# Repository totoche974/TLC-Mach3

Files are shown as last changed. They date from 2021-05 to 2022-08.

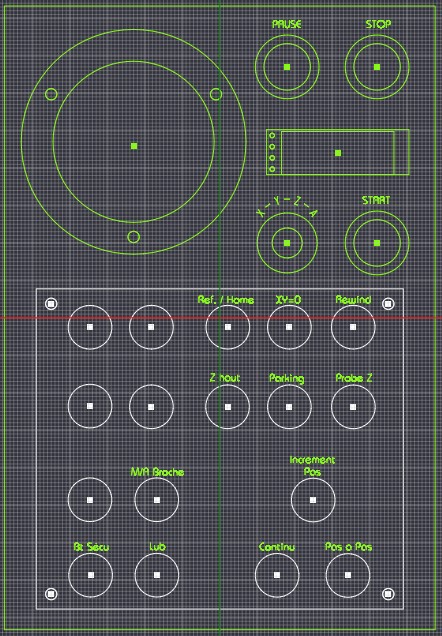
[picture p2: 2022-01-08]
doc/face_avant_TLC.jpg

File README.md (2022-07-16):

# TLC-Mach3

Ce projet héberge tout ce qu'il faut pour construire une télécommande de CNC.

## Composition de la télécommande

- 16 touches configurable via le fichier commandClavier.cpp
- 3 touches STOP , PAUSE , START 
- 1 touche de sécurité
- 1 afficheur LCD 
- 1 manivelle encodeur pour de déplacement des axes XYZA
- 1 sélecteur d'axe rotatif 4 positions
- 1 bouton poussoir pour la visu de la batterie

TODO : image montage fritzing

# Lancer le projet

## Environnement de travail

VS Code
plateformIO
Les lib externes utilisés et leur rôle

doxygen

## Génération de la documentation

Pour générer la documentation :
```shell
doxygen doxygen.config
```

# Matériel

## Schéma

Schéma de la carte "ESP32 HUZZAH FEATHER32"

Nous utilisons la carte Adafruit Huzzah ESP32 Feather:
Adafruit Huzzah ESP32 Feather Schéma de Adafruit Huzzah ESP32 Feather

## Batterie

Pour la batterie on utilise, 2 LiPo 18650 de 3Amp câblé en // 
surveillé par un module MAX17043, qui nous donne le voltage ainsi que le %
de charge restante.

Arrivé à 20% de charge restante, une led clignotante signale qu'il faut
commencer la recharge de la baterie

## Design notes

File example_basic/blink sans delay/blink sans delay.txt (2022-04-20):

/* Blink without Delay

Fait clignoter une LED connectée à une broche numérique en sortie
sans utiliser la fonction delay(). Ainsi, un autre code peut être exécuté,
sans être bloqué par le code de gestion de la LED.

La LED est connectée à la broche 13.

 créé en 2005
 par David A. Mellis
 modifié 8 Feb 2010
 par Paul Stoffregen

 Cet exemple est dans le domaine public.
Traduction française par X. HINAULT - www.mon-club-elec.fr

 http://www.arduino.cc/en/Tutorial/BlinkWithoutDelay
 */

/////////////////////// 1. Entête déclarative ///////////////////////////

// Les constantes ne changent pas durant le programme.
// Utilisée ici pour définir la numéro de la broche :

const int ledPin =  13;      // crée un identifiant pour la broche utilisée avec la LED

// Les variables sont modifiées au cours du programme
int ledState = LOW;             // ledState est utilisée pour fixer l'état de la LED (HIGH/LOW)

// les variables suivantes sont de type long car le temps, mesuré en millisecondes
// devient rapidement un nombre qui ne peut pas être stocké dans un type int.

long previousMillis = 0;        // variable pour mémoriser le temps écoulé depuis le dernier changement de la LED
long interval = 1000;           //intervalle de clignotement de la LED (en millisecondes)

///////////////////// 2. Fonction d'initialisation Setup ///////////////////////

void setup() {

  // configure la broche numérique en SORTIE
  pinMode(ledPin, OUTPUT);      

}

////////////////// 3. Fonction principale Loop /////////////////////////////

void loop()
{
  // Ici, mettre le code que vous voulez exécuter tant que la LED clignote

  // Vérifie si le délai est écoulé depuis le dernier changement d'état de la LED
  // C'est le cas si la différence entre la valeur courante renvoyée par millis()
  // et la valeur de la variable du temps du dernier changement d'état de la LED
  // est supérieure à la valeur de l'intervalle de clignotement.

  unsigned long currentMillis = millis(); // stocke la valeur courante de la fonction millis()

  if(currentMillis - previousMillis > interval) {

    // mémorise la valeur de la fonction millis()
    previousMillis = currentMillis;  

    // inverse la variable d''état de la LED
    if (ledState == LOW)
      ledState = HIGH;
    else
      ledState = LOW;

    // modifie l'état de la LED
    digitalWrite(ledPin, ledState);
  }
}

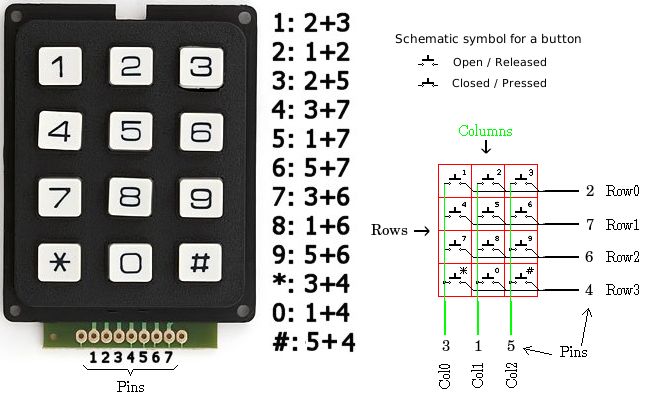
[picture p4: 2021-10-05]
doc/cablage_clavier_4x3.jpg

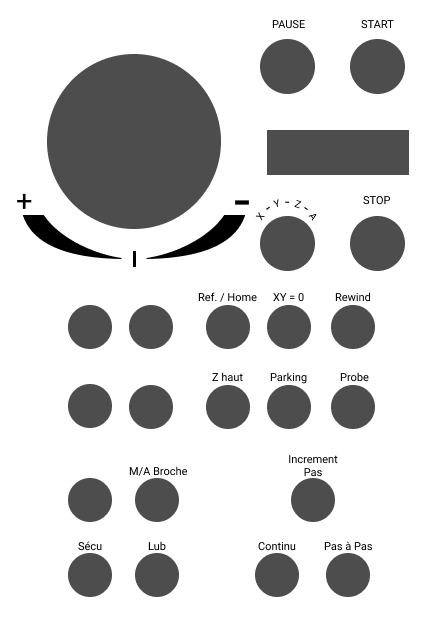
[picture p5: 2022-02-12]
doc/face_avant.png

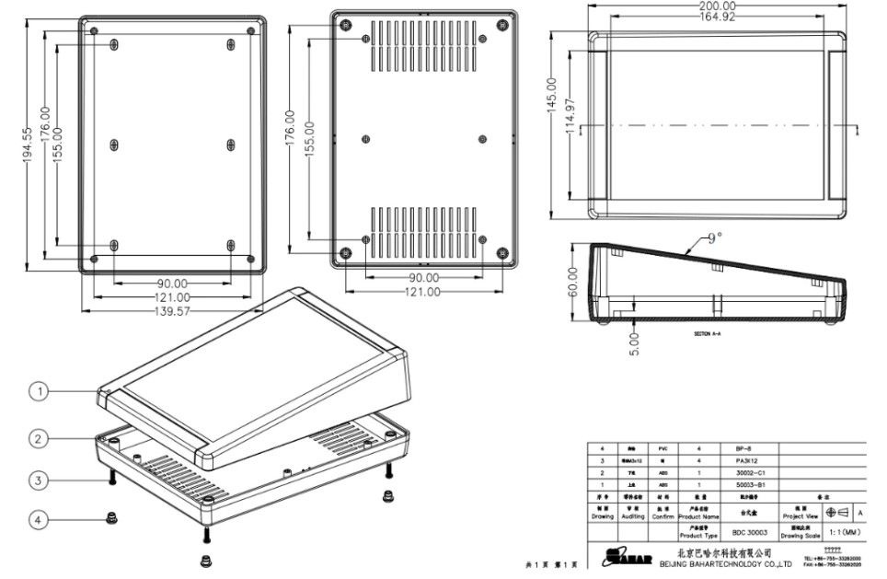
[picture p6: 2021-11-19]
doc/boitier_TLC.jpg

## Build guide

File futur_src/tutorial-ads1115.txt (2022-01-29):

httpspassionelectronique.frtutorial-ads1115

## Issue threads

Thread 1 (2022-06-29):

Délai d'affichage : changement d'axe

frozar, 2022-06-29:
Avoir l'affichage du changement d'axe lorsqu'il a lieu.

Le délai d'affichage actuelle semble empêcher la mise à jour du message qui devrait apparaître sur l'écran.

Closed 2022-06-29.

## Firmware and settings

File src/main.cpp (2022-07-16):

/**
 * @file main.cpp
 * @author Gaston, Frozar, Gilles
 * @brief Télécommande bluetooth pour mach3
 */

#include <Arduino.h>
#include <Keypad.h>
#include <BleKeyboard.h>
#include <AiEsp32RotaryEncoder.h>
#include <Wire.h>
#include <Keypad_I2C.h>
// #include <MAX1704X.h>

#include "commandClavier.h"
#include "boutonMach3.h"
#include "manivelle.h"
#include "selector.h"
#include "screen.h"
#include "sleep.h"
#include "setup_i2c.h"
#include "lipo.h"
#include "WiFi.h"

// SFE_MAX1704X lipo(MAX1704X_MAX17043);

/**
 * @brief Bluetooth keyboard variable
 *
 */
BleKeyboard keyboard("ESP32 Bluetooth", "Espressif", 80);

/**
 * @brief Screen variable
 *
 */
Adafruit_SSD1306 *display = NULL;

/**
 * Time to handle sleep mode
 *
 */

long timestampOrigin;

void setup()
{
  Serial.begin(115200);
  while (!Serial)
  { /*wait*/
  }
  Serial.println("Starting Télécommande BLE mach3");

  keyboard.begin();

  initCommandClavier();
  initManivelle();
  initI2C();

  initScreen();
  initLipo();

  // Bouton de sécurité pour la manivelle et le clavier
  pinMode(PIN_SECU_BT, INPUT_PULLUP);
  pinMode(PIN_START_BT, INPUT_PULLUP);
  pinMode(PIN_PAUSE_BT, INPUT_PULLUP);
  pinMode(PIN_ARRET_BT, INPUT_PULLUP);

  pinMode(PIN_AXE_X, INPUT_PULLUP);
  pinMode(PIN_AXE_Y, INPUT_PULLUP);
  pinMode(PIN_AXE_Z, INPUT_PULLUP);
  pinMode(PIN_AXE_A, INPUT_PULLUP);

  pinMode(PIN_LED_LIPO_ALERT, OUTPUT);
  digitalWrite(PIN_LED_LIPO_ALERT, LOW);

  pinMode(PIN_BT_VISU_CHARGE_LIPO, INPUT_PULLUP);
  // digitalWrite(PIN_BT_VISU_CHARGE_LIPO, HIGH);

  initSleep();

  screenSendMessage("TLC-M3 ON");

  timestampOrigin = millis();
}

void checkBluetoothIsConnected()
{
  if (keyboard.isConnected())
  {
    printf("Bluetooth connected\n");
  }
  else
  {
    printf("Bluetooth NOT connected\n");
  }
}

void DisableWifi()
{
  WiFi.disconnect(true); // Disconnect from the network
  WiFi.mode(WIFI_OFF);   // Switch WiFi off
}

void loop()
{
  long elapseTime = millis() - timestampOrigin;

  if (1000 < elapseTime)
  {
    checkBluetoothIsConnected();
    timestampOrigin = millis();
  }

  boutonVisuChargeLipo();

  checkMainBouton();

  manivelle();

  runCommandClavier();

  shouldSleep();
  ledAlertShouldBlink();

  loopScreen();
}

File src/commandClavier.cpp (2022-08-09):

/**
 * @file commandClavier.cpp
 */

#include <Arduino.h>
#include <Keypad.h>
#include <BleKeyboard.h>
#include <Keypad_I2C.h>

#include "commandClavier.h"

#include "screen.h"
#include "boutonMach3.h"
#include "sleep.h"
#include "axe.h"
#include "lipo.h"

extern BleKeyboard keyboard;

const uint8_t KEYPAD_ADDRESS = 0x27;

const byte ROWS = 4; // 4 lignes
const byte COLS = 4; // 4 colonnes
char keys[ROWS][COLS] = {
    {'1', '2', '3', 'A'},
    {'4', '5', '6', 'B'},
    {'7', '8', '9', 'C'},
    {'E', '0', 'F', 'D'}};

// Digitran keypad, bit numbers of PCF8574 i/o port
const byte lig_1 = 0;
const byte lig_2 = 1;
const byte lig_3 = 2;
const byte lig_4 = 3;

const byte col_1 = 4;
const byte col_2 = 5;
const byte col_3 = 6;
const byte col_4 = 7;

byte rowPins[ROWS] = {lig_1, lig_2, lig_3, lig_4};
byte colPins[COLS] = {col_1, col_2, col_3, col_4};

Keypad_I2C keypad(makeKeymap(keys), rowPins, colPins, ROWS, COLS, KEYPAD_ADDRESS, PCF8574, &Wire);

void initCommandClavier()
{
  keypad.begin();
  keypad.setHoldTime(1);
}

void Command_1(char key)
{
  Serial.print("key = ");
  Serial.println(key);
  screenSendMessage("Rembobinne");
  keyboard.press(KEY_LEFT_CTRL);
  keyboard.write(KEY_F12);
  delay(50);
  keyboard.releaseAll(); // touche Ctrl + touche F12
}

void Command_2(char key)
{
  Serial.print("key = ");
  Serial.println(key);
  screenSendMessage("  Z Haut");
  keyboard.press(KEY_F3);
  delay(50);
  keyboard.release(KEY_F3); // touche F3
}

void Command_3(char key)
{
  Serial.print("key = ");
  Serial.println(key);
  screenSendMessage(" Parking");
  keyboard.press(KEY_F7);
  delay(50);
  keyboard.release(KEY_F7); // touche F7
}

void Command_4(char key)
{
  Serial.print("key = ");
  Serial.println(key);
  screenSendMessage("Lubrifier");
  keyboard.press(KEY_LEFT_CTRL);
  keyboard.write('f');
  delay(50);
  keyboard.releaseAll(); // touche Ctrl + touche "F"
}

void Command_5(char key)
{
  Serial.print("key = ");
  Serial.println(key);
  screenSendMessage("M/A Broche");
  keyboard.press(KEY_F5);
  delay(50);
  keyboard.release(KEY_F5); // touche F5 - M/A broche
}

void Command_6(char key)
{
  Serial.print("key = ");
  Serial.println(key);
  screenSendMessage(" Probe Z");
  keyboard.press(KEY_F6);
  delay(50);
  keyboard.release(KEY_F6); // touche F3
}

void Command_7(char key)
{
  Serial.print("Key = ");
  Serial.println(key);
  screenSendMessage("XY=0 Work");
  keyboard.press(KEY_F2);
  delay(50);
  keyboard.release(KEY_F2); // touche F2
}

void Command_8(char key) // touche F8 - Choix du pas :2mm,1mm,0.5mm,0.25mm,0.1mm,0.01mmmm,0.001mm,0.0001mm
{
  Serial.print("key = ");
  Serial.println(key);
  screenSendMessage("Select Pas");
  keyboard.press(KEY_F8); // touche F8
  delay(50);
  keyboard.release(KEY_F8);
}

void Command_9(char key) // touche Ctrl + touche "J" - choix du mode : pas à pas, continu, mpg
{
  Serial.print("key = ");
  Serial.println(key);
  screenSendMessage("Mod. manuel");
  keyboard.press(KEY_LEFT_CTRL); // touche Ctrl
  keyboard.write(74);            // touche "J"
  delay(50);
  keyboard.releaseAll();
}

void Command_0(char key)
{
  Serial.print("key = ");
  Serial.println(key);
  screenSendMessage("RaZ XY = 0");
  keyboard.press(KEY_F9);
  delay(50);
  keyboard.release(KEY_F9); // touche F9
}

void Command_A(char key)
{
  Serial.print("key = ");
  Serial.println(key);
  screenSendMessage(" Home");
  keyboard.press(KEY_F4);
  delay(50);
  keyboard.release(KEY_F4); // touche F4
}

void Command_B(char key)
{
  Serial.print("key = ");
  Serial.println(key);
  screenSendMessage(" Ref. XYZ");
  keyboard.press(KEY_LEFT_CTRL);
  delay(50);
  keyboard.release(KEY_F8); // touche Ctrl + F8
}

void Command_C(char key)
{
  Serial.print("key = ");
  Serial.println(key);
  screenSendMessage("C: Not used");
}

void Command_D(char key)
{
  Serial.print("key = ");
  Serial.println(key);
  screenSendMessage("D: Not used");
}

// extern SFE_MAX1704X lipo;

void Command_E(char key)
{
  Serial.print("key = ");
  Serial.println(key);
  screenSendMessage("Pas a pas"); // Déplacement pas a pas
  keyboard.press(KEY_LEFT_CTRL);  // touche CTRL
}

void Command_F(char key)
{
  Serial.print("key = ");
  Serial.println(key);
  screenSendMessage("Dep.Rapide"); // Déplacement rapide
  keyboard.press(KEY_RIGHT_SHIFT); // touche MAJ
}

/**
 * @brief Detection de l'appui long ou court pour la mise à zéro des axes
 * Si BT pressé, < de 300ms éxécution de la remise à zéro de tous les axes
 * si BT préssé > de 300ms , remise à zéro de l'axe sélectionné
 *
 *
 */

boolean tempoActive = false;
unsigned long tempoDepart;
#define THRESHOLD_SHORT_HOLD_TIME 300 // Durée minimum de l'appui sur le bouton
const uint8_t NB_SHORT_LONG_PRESS_KEY = 1;
char listShortLongKey[NB_SHORT_LONG_PRESS_KEY] = {'0'};

// Dans le cas où on souhaite ajouter la touche '1' pour qu'elle
// gère appui court / appui long.
// const uint8_t NB_SHORT_LONG_PRESS_KEY = 2;
// char listShortLongKey[NB_SHORT_LONG_PRESS_KEY] = {'0', '1'};

bool doesKeyManageShortLongPress(char key)
{
  bool found = false;
  for (int i = 0; i < NB_SHORT_LONG_PRESS_KEY; ++i)
  {
    if (listShortLongKey[i] == key)
    {
      found = true;
      break;
    }
  }
  return found;
}

enum pressState
{
  In_progress,
  Finished,
};

struct shortPressedResult
{
  pressState state;
  bool isShort;
};

shortPressedResult isShortPressed()
{
  shortPressedResult res;
  // Serial.println("keypad.getState() : " + String(keypad.getState()));
  // Si le bouton est enfoncé,
  if (!tempoActive && (keypad.getState() == PRESSED))
  {
    tempoActive = true;
    tempoDepart = millis();
    // Serial.println("on démare la temporisation");
    // Serial.println("00 tempoDepart : " + String(tempoDepart));
  }

  // Si le bouton est relache,
  if (tempoActive && (keypad.getState() == RELEASED))
  {
    tempoActive = false;
    unsigned long tempoStop = millis();
    unsigned long elapseTime = tempoStop - tempoDepart;
    // Serial.println("on ARRETE la temporisation");
    // Serial.println("11 tempoDepart : " + String(tempoDepart));
    // Serial.println("tempoStop : " + String(tempoStop));
    // Serial.println("elapseTime : " + String(elapseTime));
    if (elapseTime < THRESHOLD_SHORT_HOLD_TIME)
    {
      res.state = pressState::Finished;
      res.isShort = true;
      return res;
    }
    else
    {
      res.state = pressState::Finished;
      res.isShort = false;
      return res;
    }
  }

  res.state = pressState::In_progress;
  res.isShort = false;
  return res;
}
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

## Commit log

2021-05-01 Create config.h
    Fichier de configuration
2021-05-01 MaJ electronique
    Rajout 2 résistances de 10K.
2021-10-02 Switch, rotacteur, encoder fonctionnel.
2021-10-05 ajout lib I2C
2021-10-16 Create Tension batterie
2021-10-16 Add basic example keypad I2C
2021-10-16 Bugfix : manivelle internal state.
    [manivelle.cpp]
2021-10-30 Move Tension batterie
2021-11-06 Add scan I2C example.
2021-11-27 Manage short and long press.
    [commandClavier.cpp, manivelle.cpp]
2022-01-08 Update PIN positions.
2022-01-08 sleep processeur 4mhz
    Baisse de la fréquence quand le cpu passe en sommeil
2022-01-29 Add the complete schema of the telecomande
    [telecommande_sketch.fzz]
2022-01-29 Moving fritzing schema files to 'doc' directory
    [telecommande_sketch.fzz]
2022-02-12 Ajout de documentation. Nouveau schema pour Adafruit Huzzah ESP32 feather
    [complete_schema_doit_esp_devkit.fzz, complete_schema_esp32_feather.fzz]
2022-02-12 Refaire la configuration des PIN pour l'adapter à la carte Huzzah esp32
2022-02-12 Mise a jour du schema huzzah esp32
    [complete_schema_esp32_feather.fzz]
2022-03-05 Programme pour consommer la batterie et récolter des points.
2022-03-07 Add documentation about batterie and the currently used ESP32.
2022-03-12 Button * : affiche l'état de la baterrie.
2022-06-29 Create file for lipo.
2022-06-29 Add blink if under a given state of charge threshold.
2022-06-30 MaJ lipo
    choix voltage et % batterie
2022-07-02 modif sur visu lipo
    pose d'un bp exterieur
2022-07-04 MàJ visu LiPo
    MàJ visu LiPo
2022-07-16 Fix display of voltage and charge of battery. Wake up if lipo button is pressed.
    [commandClavier.cpp, lipo.cpp, screen.cpp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]
2022-07-16 Update README. Shut down Led alert on sleep.
2022-08-06 Sorti des bouton E et F.
2022-08-06 Update commandClavier.cpp
    definition des touches CTRL et SHIFT
